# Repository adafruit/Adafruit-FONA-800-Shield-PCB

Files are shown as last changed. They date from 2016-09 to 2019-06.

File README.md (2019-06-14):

## Adafruit FONA 800 Shield PCB

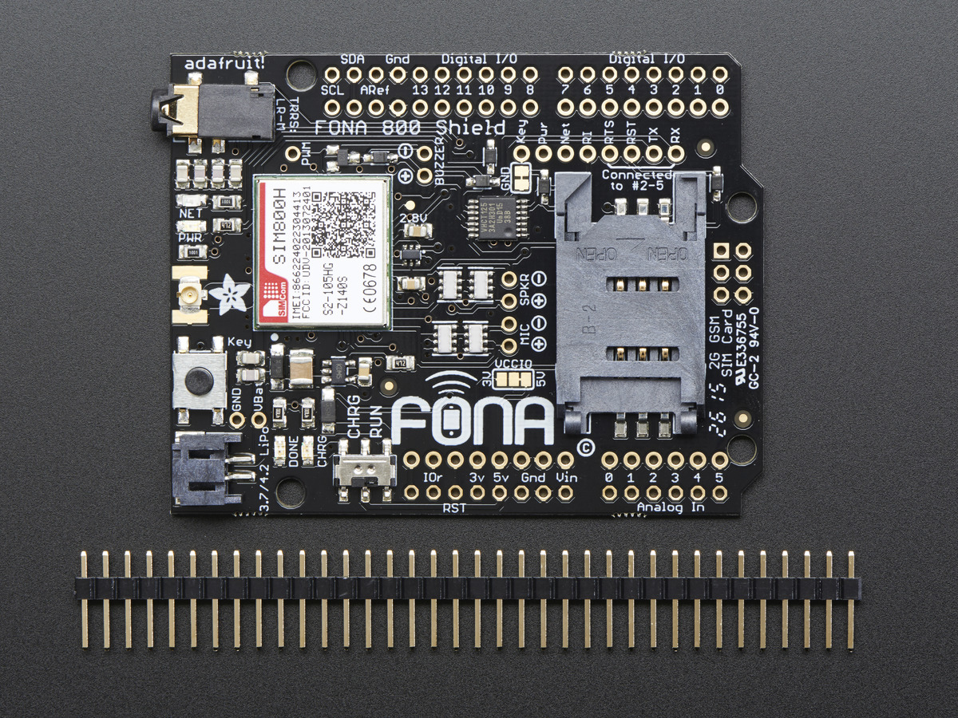
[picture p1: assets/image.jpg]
<a href="http://www.adafruit.com/products/2468"><br/>
Click here to purchase one from the Adafruit shop</a>

PCB files for the Adafruit FONA 800 Shield. Format is EagleCAD schematic and board layout
* https://www.adafruit.com/products/2468

### DESCRIPTION
Ring, Ring! Who's that callin'? It's your microcontroller! Introducing Adafruit FONA 800 Shield, an adorable all-in-one cellular phone shield that lets you add voice, text, SMS and data to your project in an easy to use pluggable shield.

This shield fits on top of any classic Arduino or compatible, and packs a surprising amount of technology into it's little frame. At the heart is a GSM cellular module (we use the latest SIM800) the size of a postage stamp. This module can do just about everything. 

If you want a Shield Version with GPS, check out the Adafruit FONA 808 Shield - Mini Cellular GSM + GPS for Arduino [click here](https://www.adafruit.com/product/2636).

If you just want a plain FONA breakout, [click here](https://www.adafruit.com/product/1946).

Quad-band 850/900/1800/1900MHz - connect onto any global GSM network with any 2G SIM (in the USA, T-Mobile is suggested)
Make and receive voice calls using a headset OR an external 8Ω speaker + electret microphone
Send and receive SMS messages
Send and receive GPRS data (TCP/IP, HTTP, etc.)
Scan and receive FM radio broadcasts (yeah, we don't exactly know why this was included but it works really well)
PWM/Buzzer vibrational motor control
AT command interface with "auto baud" detection
Sounds delicious, right? So we plated this fine module onto a shield with all the extras you need to make your next project shine.

### License

Adafruit invests time and resources providing this open source design, please support Adafruit and open-source hardware by purchasing products from [Adafruit.com](https://www.adafruit.com)!

Designed by Adafruit Industries. 

Creative Commons Attribution, Share-Alike license, check license.txt for more information All text above must be included in any redistribution - 
See license.txt for more information.

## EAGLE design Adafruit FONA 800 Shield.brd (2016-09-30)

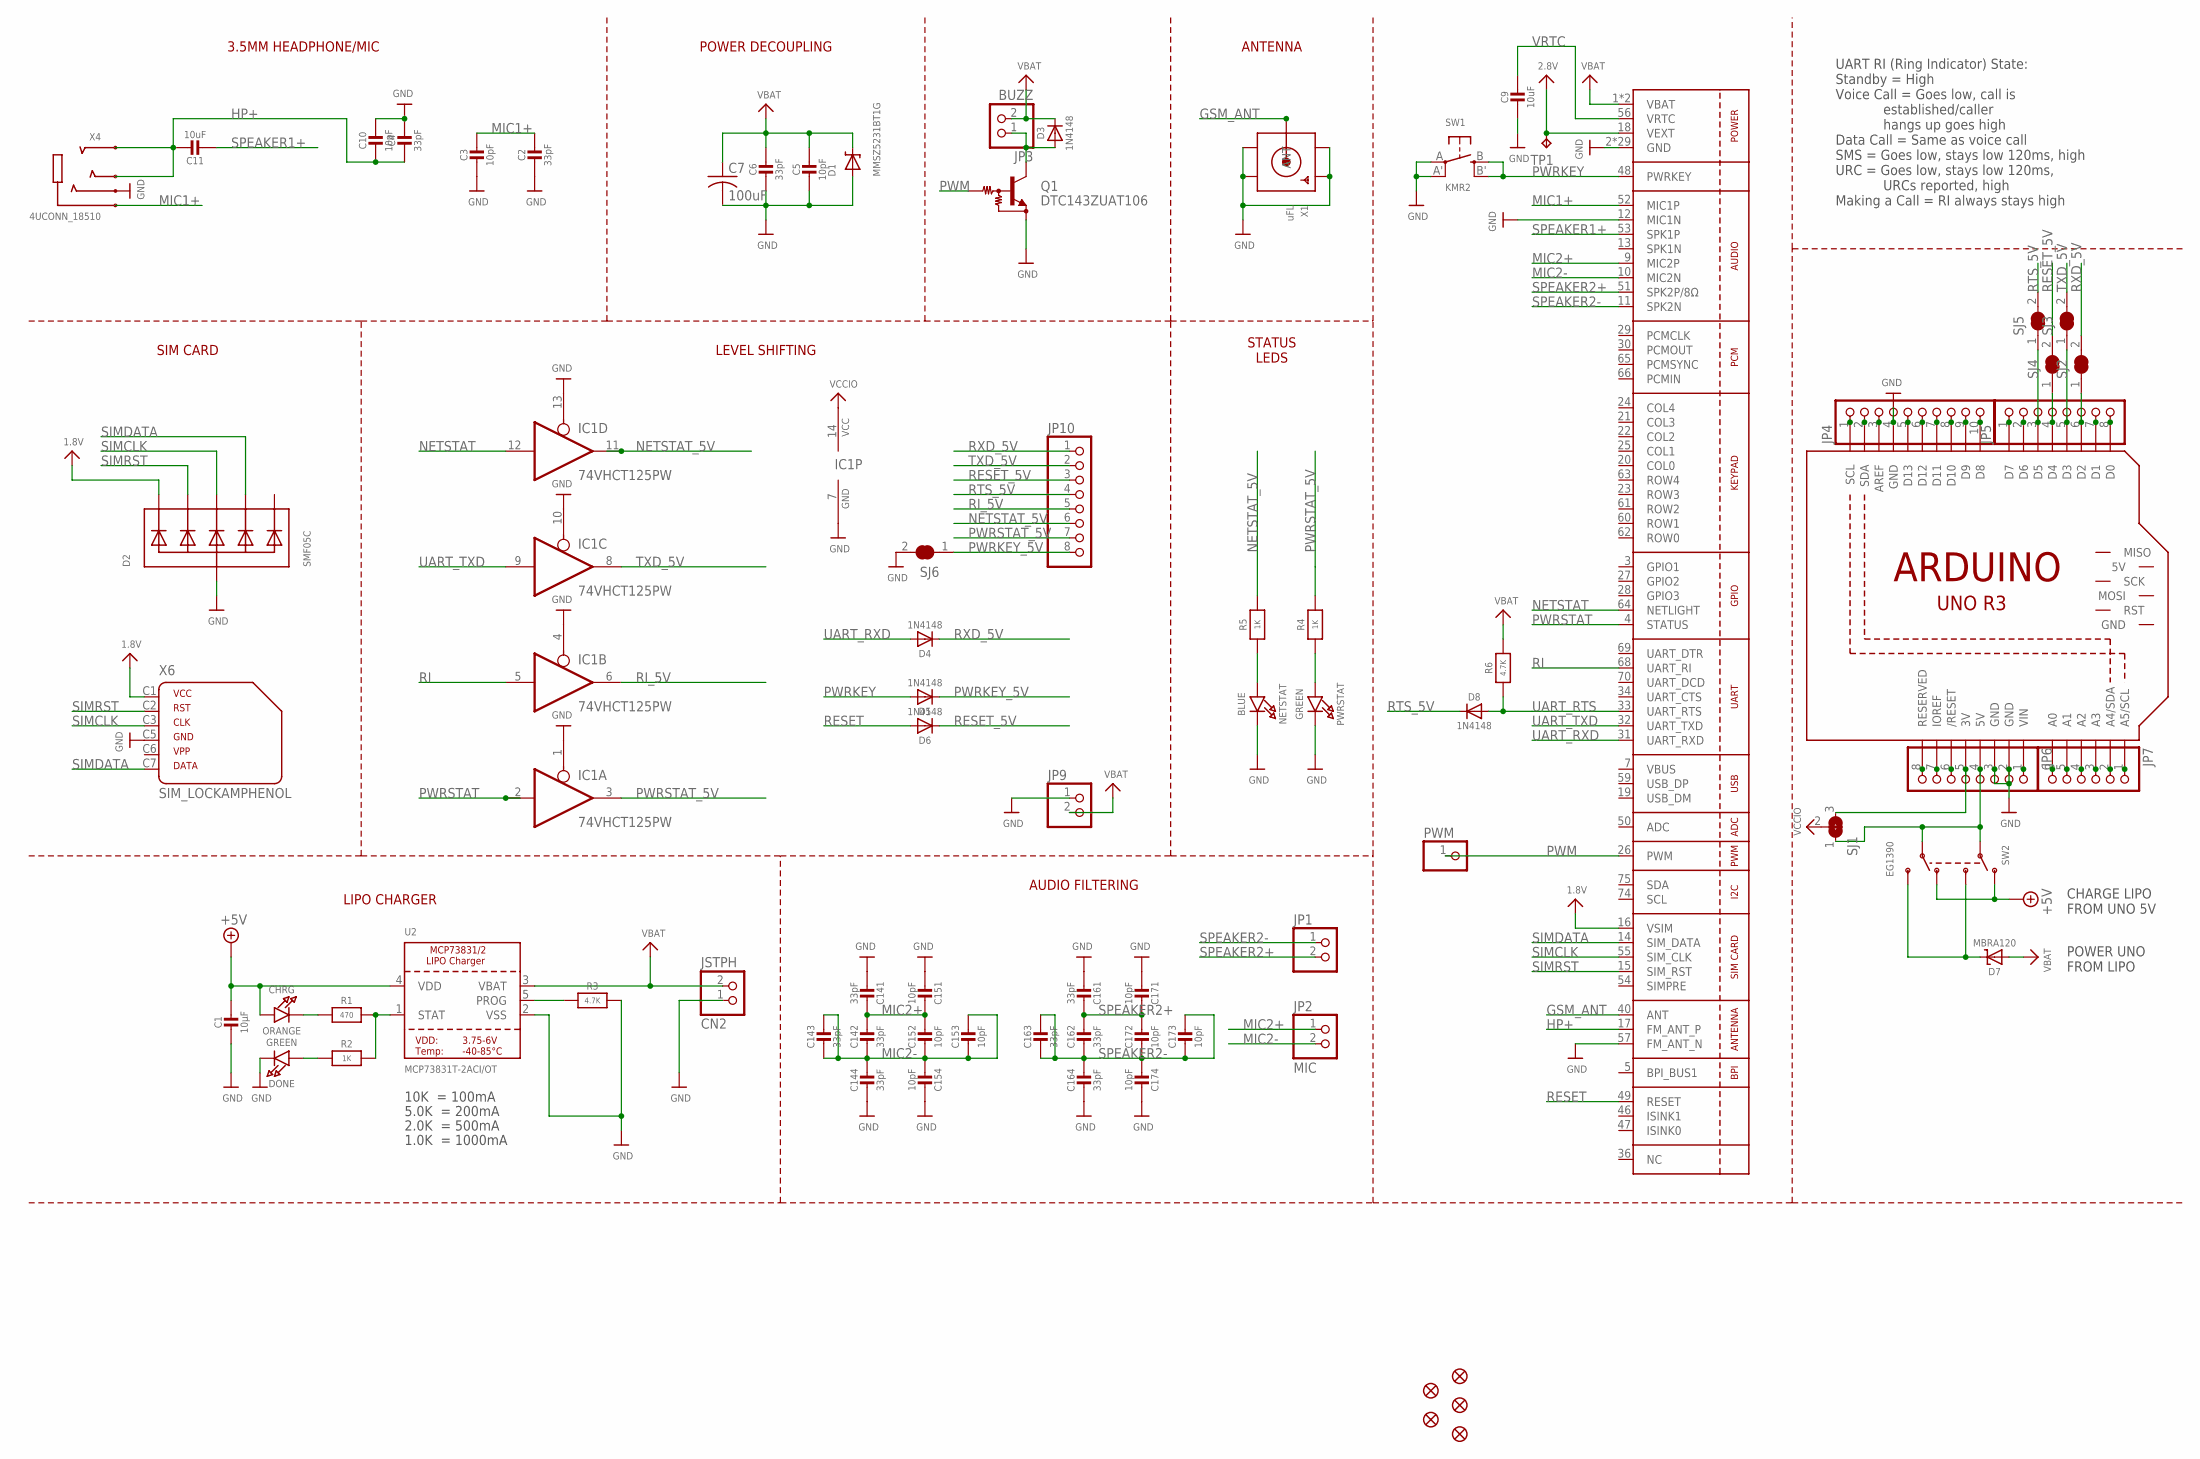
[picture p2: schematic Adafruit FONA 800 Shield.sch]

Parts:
C1: 10µF; 0805-NO
C2, C4, C6: 33pF; 0805-NO
C3, C5, C10: 10pF; 0805-NO
C7: 100uF; C1210
C9, C11: 10uF; 0805-NO
C14, C16: 33pF; RESPACK_4X0603
C15, C17: 10pF; RESPACK_4X0603
CHRG: ORANGE; CHIPLED_0805_NOOUTLINE
CN2: JSTPH; JSTPH2
D1: MMSZ5231BT1G; SOD-123
D2: SMF05C; SOT363
D3, D4, D5, D6, D8: 1N4148; SOD-323
D7: MBRA120; SOD-123
DONE: GREEN; CHIPLED_0805_NOOUTLINE
FID1, FID2, FID3, FID4, FID5: FIDUCIAL""; FIDUCIAL_1MM
IC1: 74VHCT125PW; TSSOP14
JP1, JP9: HEADER-1X2ROUND; 1X02_ROUND
JP2: MIC; 1X02_ROUND
JP3: BUZZ; 1X02_ROUND
JP4: HEADER-1X1070MIL; 1X10_ROUND70
JP5, JP6, JP10: HEADER-1X876MIL; 1X08_ROUND_76
JP7: HEADER-1X676MIL; 1X06_ROUND_76
M1: ARDUINO_R3_ICSP_NODIM; ARDUINOR3_ICSP_NODIM
NETSTAT: BLUE; CHIPLED_0805_NOOUTLINE
PWM: PINHD-1X1CB; 1X01-CLEANBIG
PWRSTAT: GREEN; CHIPLED_0805_NOOUTLINE
Q1: DTC143ZUAT106; SC59-BEC
R1: 470; 0805-NO
R2, R4, R5: 1K; 0805-NO
R3, R6: 4.7K; 0805-NO
SJ1: SOLDERJUMPER_2WAY; SOLDERJUMPER_2WAY_OPEN_NOPASTE
SJ2, SJ3, SJ4, SJ5, SJ6: SOLDERJUMPER_CLOSED; SOLDERJUMPER_CLOSEDWIRE
SW1: KMR2; EVQ-Q2
SW2: EG1390
TP1: TPTP11R; TP11R
U1: SIM800H/L; SIM800L
U2: MCP73831T-2ACI/OT; SOT23-5
X1: uFL; SMA_EDGELAUNCH_UFL
X4: 4UCONN_18510
X6: SIM_LOCKAMPHENOL; C707_10M006_512_2

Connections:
1.8V: D2.1 (C1), U1.16 (VSIM), X6.C1 (1)
2.8V: TP1.TP, U1.18 (VEXT)
3V: JP6.5, M1.3V, SJ1.3
5V: JP6.4, M1.5V, SJ1.1, SW2.P1, SW2.P2
+5V: C1.1, CHRG.A, SW2.O1, SW2.O2, U2.4 (VDD)
A0: JP7.6, M1.A0
A1: JP7.5, M1.A1
A2: JP7.4, M1.A2
A3: JP7.3, M1.A3
A4: JP7.2, M1.A4 (A4/SDA)
A5: JP7.1, M1.A5 (A5/SCL)
AREF: JP4.3, M1.AREF
BUZZ-: D3.A, JP3.1, Q1.C
D0: JP5.8, M1.D0
D1: JP5.7, M1.D1
D2: JP5.6, M1.D2, SJ2.1
D3: JP5.5, M1.D3, SJ3.1
D4: JP5.4, M1.D4, SJ4.1
D5: JP5.3, M1.D5, SJ5.1
D6: JP5.2, M1.D6
D7: JP5.1, M1.D7
D8: JP4.10, M1.D8
D9: JP4.9, M1.D9
D10: JP4.8, M1.D10
D11: JP4.7, M1.D11
D12: JP4.6, M1.D12
D13: JP4.5, M1.D13
GND: C1.2, C2.2, C3.2, C4.1, C5.2, C6.2, C7.2, C9.2, C10.1, C14.5 (2), C14.8 (2), C15.4 (1), C15.8 (2), C16.5 (2), C16.8 (2), C17.4 (1), C17.8 (2), CN2.1, D1.A, D2.2 (A), DONE.C, IC1.1 (OE), IC1.4 (OE), IC1.7 (GND), IC1.10 (OE), IC1.13 (OE), JP4.4, JP6.2, JP6.3, JP9.1, M1.GND, M1.GND@1 (GND), M1.GND@3 (GND), NETSTAT.C, PWRSTAT.C, Q1.E, R3.2, SJ6.2, SW1.A, SW1.A' (P1), U1.2 (GND), U1.6 (GND), U1.8 (GND), U1.12 (MIC1N), U1.35 (GND), U1.37 (GND), U1.38 (GND), U1.39 (GND), U1.41 (GND), U1.43 (GND), U1.44 (GND), U1.45 (GND), U1.57 (FM_ANT_N), U1.58 (GND), U1.67 (GND), U1.71 (GND), U1.72 (GND), U1.73 (GND), U1.76 (GND), U1.77 (GND), U1.78 (GND), U1.79 (GND), U1.80 (GND), U1.81 (GND), U1.82 (GND), U1.83 (GND), U1.84 (GND), U1.85 (GND), U1.86 (GND), U1.87 (GND), U1.88 (GND), U2.2 (VSS), X1.GND@1 (GND1), X1.GND@2 (GND2), X1.GND@3 (GND3), X1.GND@4 (GND4), X4.4-INNER_SLEEVE (RING1), X6.C5 (4)
GSM_ANT: U1.40 (ANT), X1.P (ANT)
HP+: C4.2, C10.2, C11.1, U1.17 (FM_ANT_P), X4.2-TIP (RING3), X4.3-OUTER_SLEEVE (RING2)
IOREF: JP6.7, M1.IOREF
MIC1+: C2.1, C3.1, U1.52 (MIC1P), X4.1-GND (TIP)
MIC2+: C14.1, C14.2 (1), C15.1, C15.2 (1), JP2.1, U1.9 (MIC2P)
MIC2-: C14.3 (1), C14.4 (1), C14.6 (2), C14.7 (2), C15.3 (1), C15.5 (2), C15.6 (2), C15.7 (2), JP2.2, U1.10 (MIC2N)
unnamed: CHRG.C, R1.1
unnamed: R1.2, R2.2, U2.1 (STAT)
unnamed: PWRSTAT.A, R4.1
unnamed: R3.1, U2.5 (PROG)
unnamed: DONE.A, R2.1
unnamed: D7.C, SW2.S1, SW2.S2
unnamed: NETSTAT.A, R5.1
NC: JP6.8, M1.RESERVED
NETSTAT: IC1.12 (I), U1.64 (NETLIGHT)
NETSTAT_5V: IC1.11 (O), JP10.6, R5.2
PWM: PWM.1, Q1.B, U1.26 (PWM)
PWRKEY: D5.A, SW1.B (S), SW1.B' (S1), U1.48 (PWRKEY)
PWRKEY_5V: D5.C, JP10.8, SJ6.1
PWRSTAT: IC1.2 (I), U1.4 (STATUS)
PWRSTAT_5V: IC1.3 (O), JP10.7, R4.2
RESET: D6.A, U1.49 (RESET)
RESET_5V: D6.C, JP10.3, SJ4.2
RI: IC1.5 (I), U1.68 (UART_RI)
RI_5V: IC1.6 (O), JP10.5
RST: JP6.6, M1.RESET (/RESET)
RTS_5V: D8.C, JP10.4, SJ5.2
RXD_5V: D4.C, JP10.1, SJ2.2
SCL: JP4.1, M1.SCL
SDA: JP4.2, M1.SDA
SIMCLK: D2.4 (C3), U1.55 (SIM_CLK), X6.C3 (3)
SIMDATA: D2.5 (C4), U1.14 (SIM_DATA), X6.C7 (6)
SIMRST: D2.3 (C2), U1.15 (SIM_RST), X6.C2 (2)
SPEAKER1+: C11.2, U1.53 (SPK1P)
SPEAKER2+: C16.1, C16.2 (1), C17.1, C17.2 (1), JP1.2, U1.51 (SPK2P/8Ω)
SPEAKER2-: C16.3 (1), C16.4 (1), C16.6 (2), C16.7 (2), C17.3 (1), C17.5 (2), C17.6 (2), C17.7 (2), JP1.1, U1.11 (SPK2N)
TXD_5V: IC1.8 (O), JP10.2, SJ3.2
UART_RTS: D8.A, R6.1, U1.33 (UART_RTS)
UART_RXD: D4.A, U1.31 (UART_RXD)
UART_TXD: IC1.9 (I), U1.32 (UART_TXD)
VBAT: C5.1, C6.1, C7.1, CN2.2, D1.C, D3.C, D7.A, JP3.2, JP9.2, R6.2, U1.1 (VBAT), U1.42 (VBAT), U2.3 (VBAT)
VBUS: U1.7 (VBUS)
VCCIO: IC1.14 (VCC), SJ1.2
VIN: JP6.1, M1.VIN
VRTC: C9.1, U1.56 (VRTC)

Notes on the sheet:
10K = 100mA
5.0K = 200mA
2.0K = 500mA
1.0K = 1000mA
UART RI (Ring Indicator) State: Standby = High Voice Call = Goes low, call is established/caller hangs up goes high Data Call = Same as voice call SMS = Goes low, stays low 120ms, high URC = Goes low, stays low 120ms, URCs reported, high Making a Call = RI always stays high
ANTENNA
POWER DECOUPLING
3.5MM HEADPHONE/MIC
SIM CARD
LEVEL SHIFTING
LIPO CHARGER
AUDIO FILTERING
STATUS LEDS
CHARGE LIPO FROM UNO 5V
POWER UNO FROM LIPO

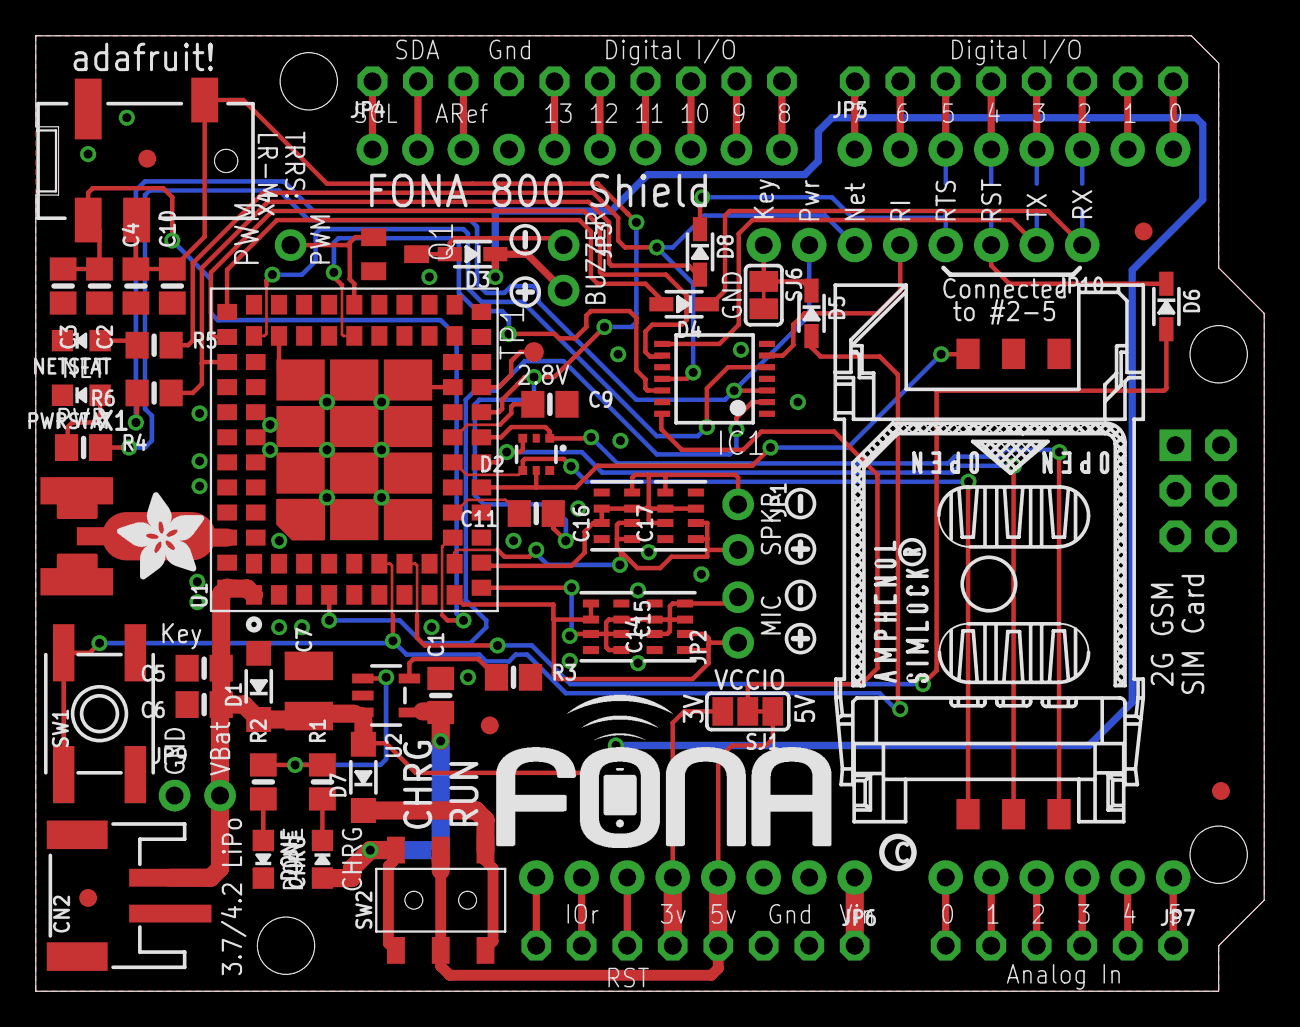
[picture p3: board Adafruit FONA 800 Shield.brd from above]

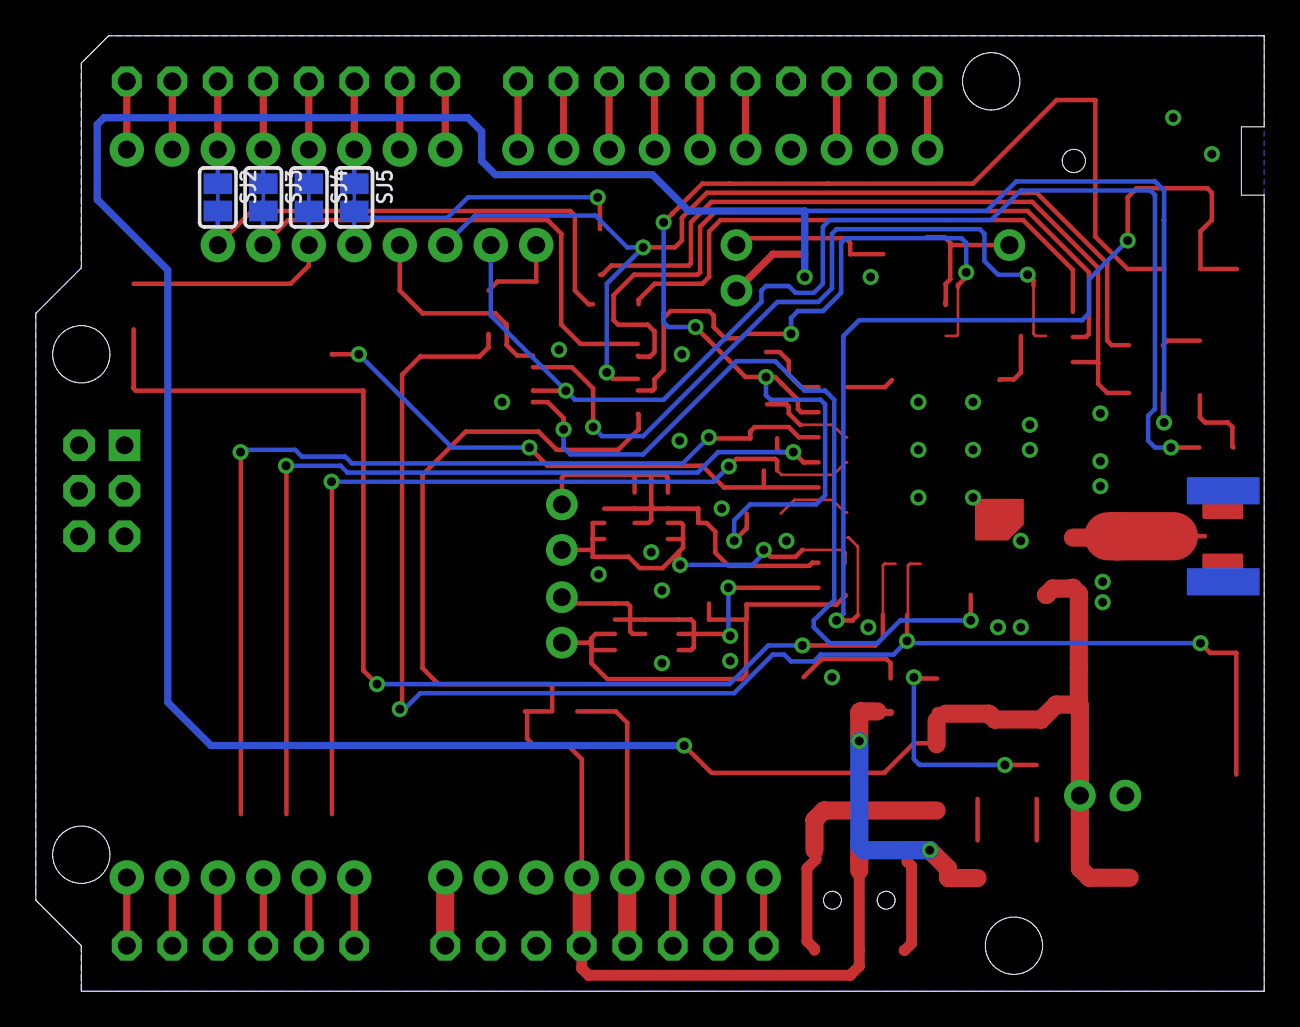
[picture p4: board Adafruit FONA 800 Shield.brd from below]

Board: 2 copper layers, 68.6 x 53.3 mm, 74 parts (4 on the bottom side), 72 nets.

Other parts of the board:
U$2, U$36, U$43: SYMBOL_PLUS
U$10: ADAFRUIT_5MM
U$26: FONA_LOGO
U$33, U$34, U$57: SYMBOL_MINUS
U$59: PCBFEAT-REV-040

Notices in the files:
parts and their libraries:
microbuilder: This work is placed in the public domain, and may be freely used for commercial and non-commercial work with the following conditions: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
